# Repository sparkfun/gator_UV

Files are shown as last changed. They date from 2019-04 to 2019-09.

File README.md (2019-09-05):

SparkFun gator:UV - micro:bit Accessory Board
========================================

SparkFun gator:UV - micro:bit Accessory Board (https://www.sparkfun.com/products/15273)

[*SparkFun gator:UV - micro:bit Accessory Board (SEN-15273)*](https://www.sparkfun.com/products/15273)

Need to apply some sunscreen? SPF 15? SPF 50? SPF 5000? It's time to consult the gator:UV, a [micro:bit](https://www.sparkfun.com/products/14208) accessory board. The gator:UV is the perfect tool to monitor the UV exposure in your next experiment. With the VEML6070, the gator:UV can easily be used to measure the levels of UVA (320-400 nm) radiation.

Repository Contents
-------------------
* **/Hardware** - Eagle design files (.brd, .sch)
* **/Production** - Production panel files (.brd)

Documentation
--------------
* **[Hookup Guide](https://learn.sparkfun.com/tutorials/sparkfun-gatoruv-hookup-guide)** - Basic hookup guide for the gator:UV.
* **[gator:UV PXT Package](https://github.com/sparkfun/pxt-gator-UV)** - PXT- package for the MakeCode gator:UV extension.

License Information
-------------------

This product is _**open source**_! 

Please review the LICENSE.md file for license information. 

If you have any questions or concerns on licensing, please visit the [SparkFun Forum](https://forum.sparkfun.com/index.php) and post a topic. For more general questions related to our gator boards, please visit this section of the forum: [Gator Products](https://forum.sparkfun.com/viewforum.php?f=162).

Distributed as-is; no warranty is given.

- Your friends at SparkFun.

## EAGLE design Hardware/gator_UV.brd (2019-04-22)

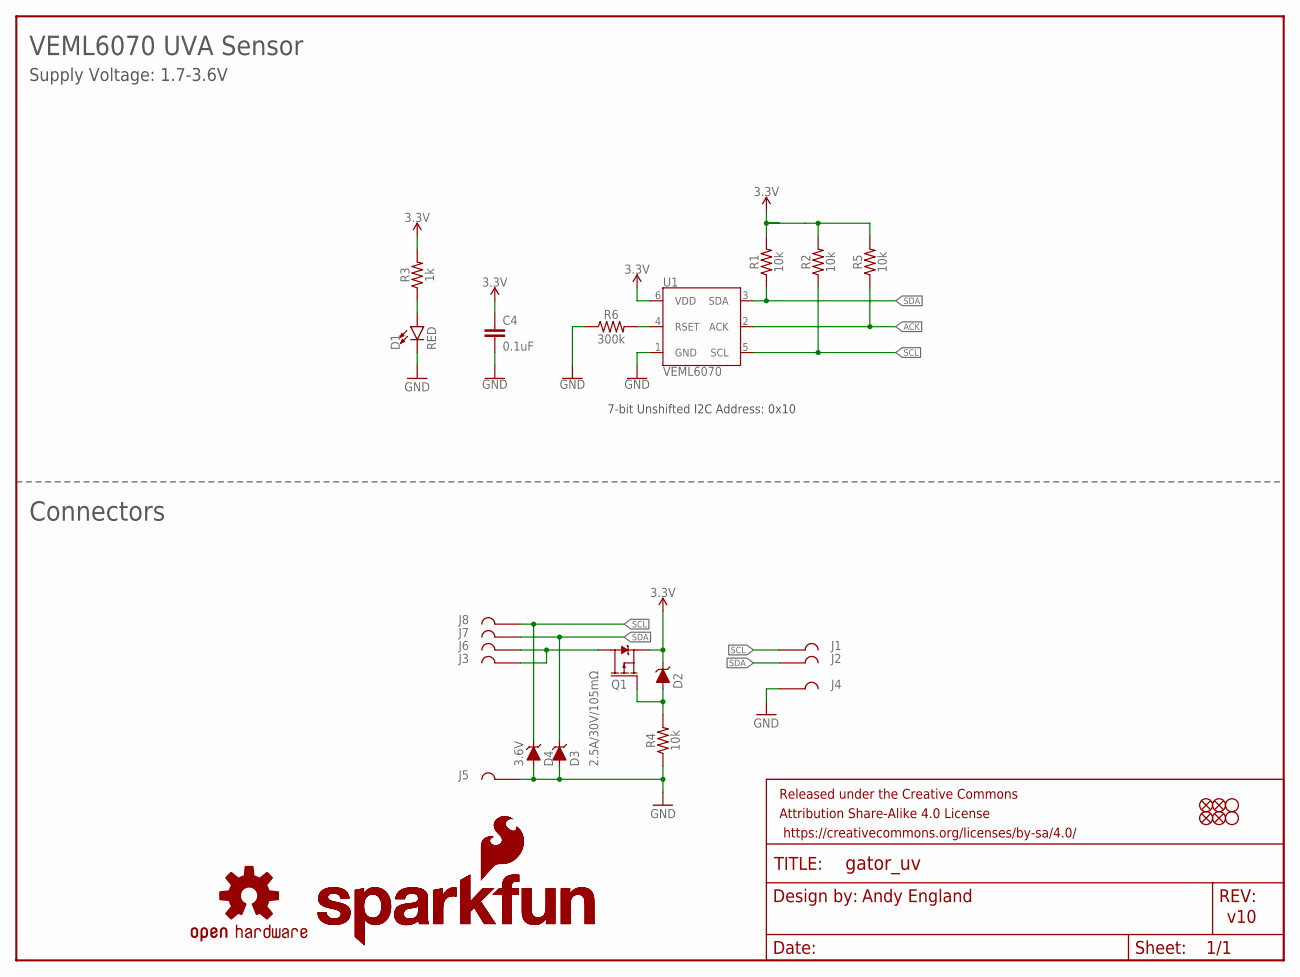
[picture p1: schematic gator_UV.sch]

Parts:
C4: 0.1uF; 0603
D1: RED; LED-0603
D2, D3, D4: 3.6V; SOD-323
FRAME1: FRAME-LETTER; CREATIVE_COMMONS
J1, J2, J3, J4, J5, J6, J7, J8: GATORGATOR_MINI; GATOR_MINI
JP2, JP5, JP6, JP7: FIDUCIALUFIDUCIAL; MICRO-FIDUCIAL
JP3, JP4: STAND-OFF
LOGO1: OSHW-LOGOMINI; OSHW-LOGO-MINI
Q1: 2.5A/30V/105mΩ; SOT23-3
R1, R2, R4, R5: 10k; 0603
R3: 1k; 0603
R6: 300k; 0603
U1: VEML6070
U$1, U$2: SFE_LOGO_NAME_FLAME.1_INCH; SFE_LOGO_NAME_FLAME_.1

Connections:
3.3V: C4.1, D2.C, Q1.2 (S), R1.2, R2.2, R3.2, R5.2, U1.6 (VDD)
ACK: R5.1, U1.2 (ACK)
GND: C4.2, D1.C, D3.A, D4.A, J4.P$2, J5.P$2, R4.1, R6.1, U1.1 (GND)
unnamed: J3.P$2, J6.P$2, Q1.3 (D)
unnamed: R6.2, U1.4 (RSET)
unnamed: D1.A, R3.1
unnamed: D2.A, Q1.1 (G), R4.2
SCL: D4.C, J1.P$2, J8.P$2, R2.1, U1.5 (SCL)
SDA: D3.C, J2.P$2, J7.P$2, R1.1, U1.3 (SDA)

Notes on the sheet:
7-bit Unshifted I2C Address: 0x10
v10
VEML6070 UVA Sensor
Connectors
Andy England
Supply Voltage: 1.7-3.6V

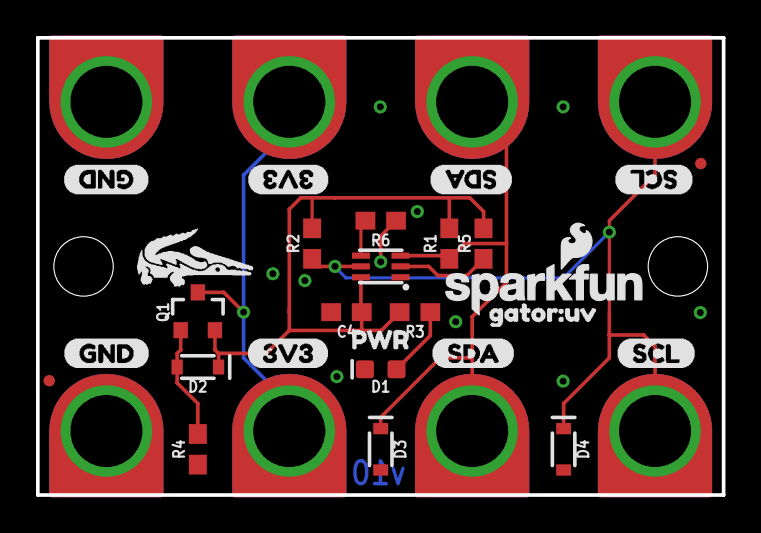
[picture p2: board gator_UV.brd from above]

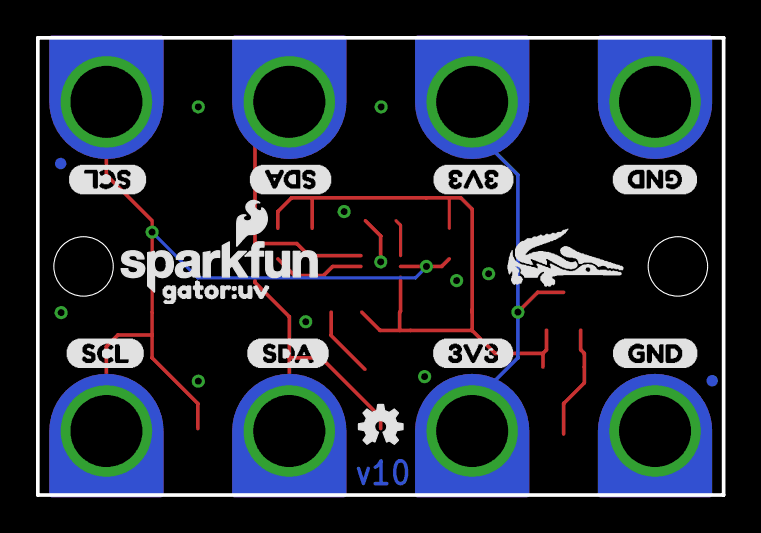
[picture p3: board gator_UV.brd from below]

Board: 2 copper layers, 38.1 x 25.4 mm, 53 parts (14 on the bottom side), 9 nets.

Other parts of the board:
U$3, U$8, U$14, U$19: 3V33
U$4, U$9, U$13, U$18: GND0
U$5, U$11, U$17, U$21: SCL2
U$6, U$24: GATOR#UV5
U$7, U$12, U$15, U$20: SDA1
U$10: ORDERING_INSTRUCTIONS
U$22, U$23: GATORBIT_FINAL_FOR_SILK#01#PNG
U$25: PWR0

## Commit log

2019-02-25 initial commit, initial layout
    [14148-Qwiic_UV_Sensor_VEML6075-Panel.GBL, 14148-Qwiic_UV_Sensor_VEML6075-Panel.GBO, 14148-Qwiic_UV_Sensor_VEML6075-Panel.GBS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]
2019-02-25 resizing and adding silk
    [Qwiic_UV_Sensor_VEML6075.brd]
2019-02-27 adding labelling, removing pullup jumper
    [Qwiic_UV_Sensor_VEML6075.brd, Qwiic_UV_Sensor_VEML6075.sch]
2019-02-28 adding protection circuitry
    [Qwiic_UV_Sensor_VEML6075.brd, Qwiic_UV_Sensor_VEML6075.sch]
2019-02-28 finalizing silk and schematic before design review
    [Qwiic_UV_Sensor_VEML6075.brd]
2019-03-01 post checklist changes
    [Board_Design_Checklist_gatoruv_v01.xls, Qwiic_UV_Sensor_VEML6075.brd, Qwiic_UV_Sensor_VEML6075.sch]
2019-03-14 updating to VEML6070
    [Qwiic_UV_Sensor_VEML6075.brd, Qwiic_UV_Sensor_VEML6075.sch]
2019-03-14 post review changes
    [Qwiic_UV_Sensor_VEML6075.brd]
2019-04-16 pre design review changes
    [Qwiic_UV_Sensor_VEML6075-2-Panel.GBL, Qwiic_UV_Sensor_VEML6075-2-Panel.GBO, Qwiic_UV_Sensor_VEML6075-2-Panel.GBS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]
2019-04-19 engineer run of checklist
    [Qwiic_UV_Sensor_VEML6075.brd, Qwiic_UV_Sensor_VEML6075.sch]
2019-04-22 qc double check changes
    [gator_UV.brd, gator_UV.sch]
2019-09-05 removing old prod folder for launch
    [14148-Qwiic_UV_Sensor_VEML6075-Panel.GBL, 14148-Qwiic_UV_Sensor_VEML6075-Panel.GBO, 14148-Qwiic_UV_Sensor_VEML6075-Panel.GBS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]

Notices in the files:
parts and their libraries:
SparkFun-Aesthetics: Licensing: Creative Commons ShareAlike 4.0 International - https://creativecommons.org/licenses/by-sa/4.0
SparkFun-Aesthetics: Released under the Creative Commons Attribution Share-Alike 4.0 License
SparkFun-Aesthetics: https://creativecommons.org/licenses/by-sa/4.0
